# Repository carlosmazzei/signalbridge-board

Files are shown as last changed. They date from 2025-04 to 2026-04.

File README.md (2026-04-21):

<!-- markdownlint-disable MD033 MD041 -->
<div align="center">
Signalbridge
Signalbridge
</div>
<!-- markdownlint-enable MD033 MD041 -->

# Signalbridge - Board




**A comprehensive, industrial-grade breakout board for the Raspberry Pi Pico with advanced I/O expansion and control capabilities.**

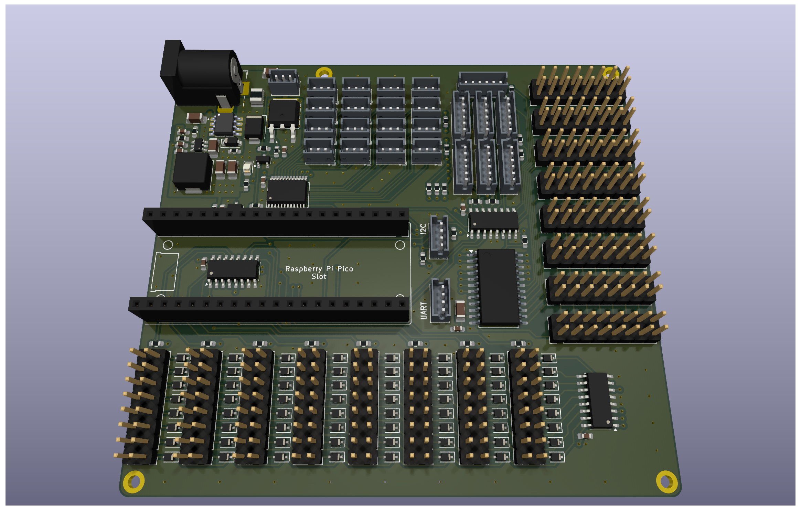
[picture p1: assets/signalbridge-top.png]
Board Render Top

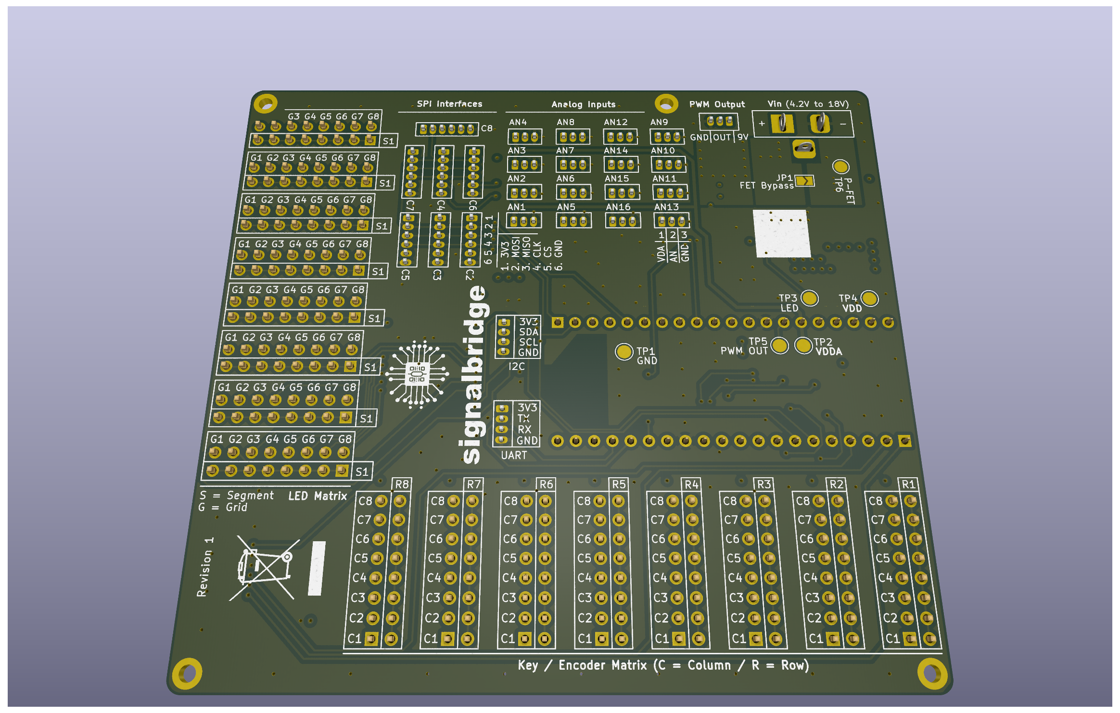
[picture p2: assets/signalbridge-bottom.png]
Board Render Bottom


## Fabricated Board

<!-- markdownlint-disable MD033 -->
<p align="center">
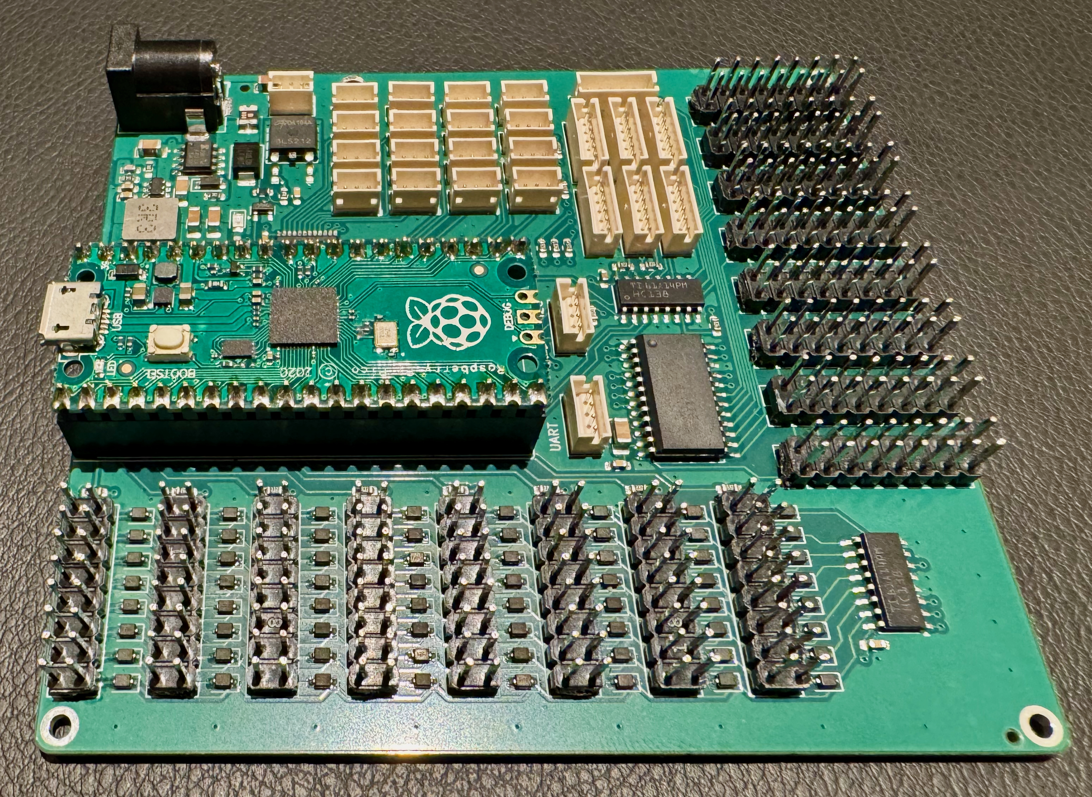
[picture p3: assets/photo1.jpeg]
Fabricated Board - Photo 1
  
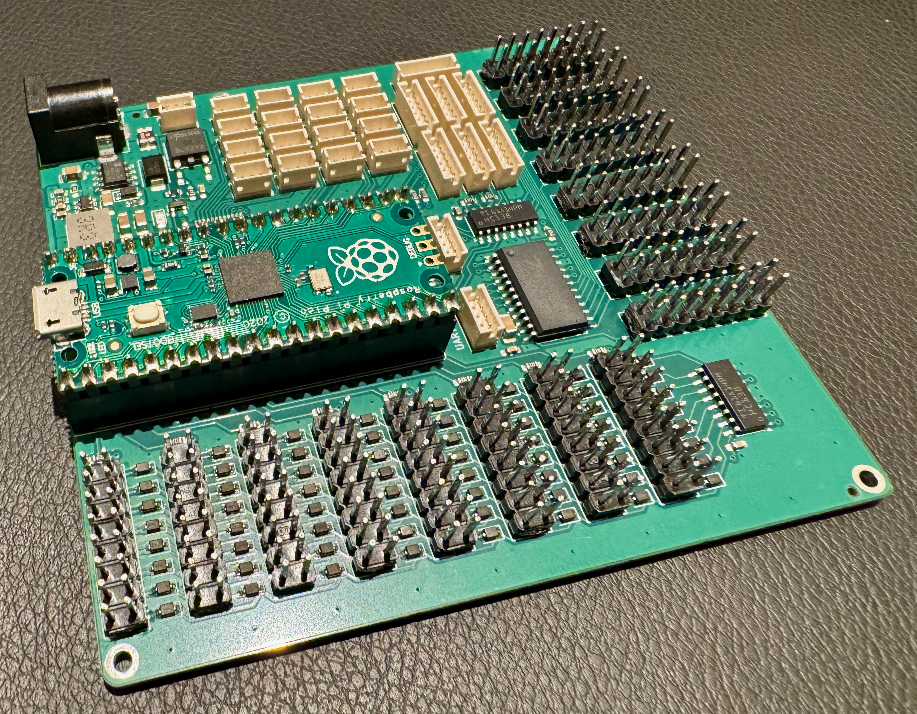
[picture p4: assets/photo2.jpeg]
Fabricated Board - Photo 2
  
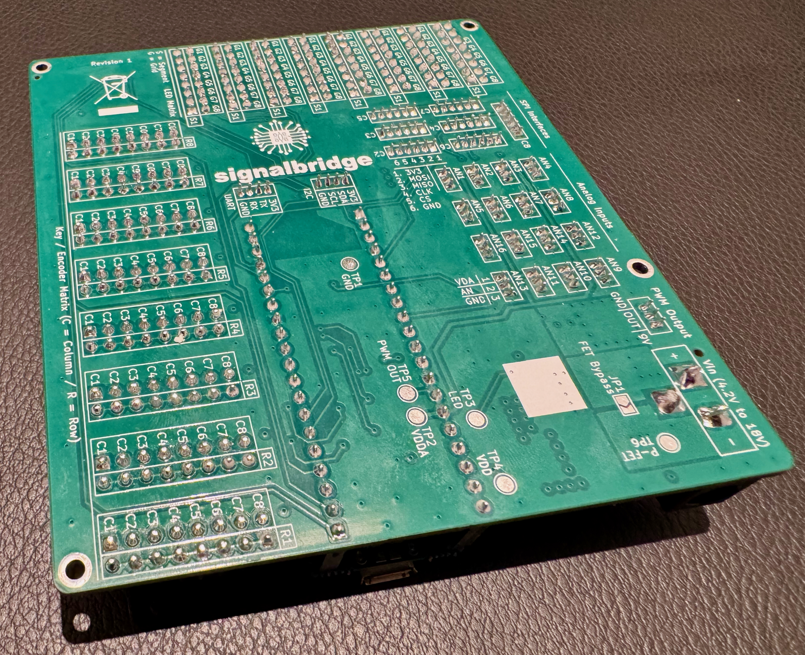
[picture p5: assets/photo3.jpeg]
Fabricated Board - Photo 3
  
</p>
<!-- markdownlint-enable MD033 -->

## Overview

Signalbridge is a feature-rich breakout board designed to unlock the full potential of the Raspberry Pi Pico microcontroller. This board transforms the Pico into a powerful controller suitable for industrial automation, IoT projects, robotics, and educational applications.

> [!TIP]
> This board is designed for the Raspberry Pi Pico.

Related repos:

- [Signalbridge breakout board](https://github.com/carlosmazzei/signalbridge-board) (This repo)
- [Signalbridge test suite](https://github.com/carlosmazzei/signalbridge-test-suite)
- [Signalbridge firmware](https://github.com/carlosmazzei/signalbridge-controller)

### Key Highlights

- **Wide Input Voltage Range**: 4.2V to 18V DC input with efficient 3.3V/3A regulation
- **16-Channel Analog Inputs**: Expandable analog reading capability through integrated multiplexer
- **8×8 Keypad Matrix**: Professional keypad interface with ESD protection
- **Multiple Communication Interfaces**: I2C, UART, and 8 SPI outputs
- **LED Display Controller**: TM1639 for driving 7-segment displays and LED matrices
- **PWM Output**: Dedicated PWM output with 3-pin connector
- **User LED**: Power-on indicator LED
- **Mounting**: 4× mounting holes for secure installation
- **Comprehensive Protection**: ESD protection on all external interfaces
- **Professional Grade**: Designed for reliability and expandability

## Project Structure

```text
signalbridge-board/
├── pi_controller.kicad_{pro,sch,pcb,dru,prl}  # Main KiCad 9 project
├── fp-lib-table, sym-lib-table                # KiCad library tables
├── fabrication-toolkit-options.json           # Fabrication-Toolkit settings
├── library/                                   # Custom symbols & footprints
├── assets/                                    # Board renders & logos
├── datasheets/                                # Component datasheets (PDF)
├── jlcpcb/                                    # Fabrication outputs (gerbers, BOM, CPL)
└── docs/
    └── PRODUCTION_CHECKLIST.md                # PCBA production & test-point checklist
```

The `jlcpcb/` folder name is referenced by `.github/workflows/release_jlcpcb.yml`; the `library/` folder and the root `pi_controller.*` files are referenced by `fp-lib-table` / `sym-lib-table`. Renaming any of these will break the project.

## Features
### Power Management

- **Input Voltage**: 4.2V to 18V DC (via barrel jack connector)
- **Regulation**: AP62300TWU buck converter providing 3.3V at up to 3A
- **Efficiency**: High-efficiency switching regulator with low dropout
- **Protection**: Input protection and power indicator LED
- **Flexibility**: Can be powered via USB or external DC supply

### Analog Inputs (16-Channel)

- **Multiplexer**: CD74HC4067 16:1 analog multiplexer
- **Resolution**: 12-bit ADC resolution (0-4095 digital values)
- **Voltage Range**: 0V to 3.3V analog input range
- **Reference**: Precision LM4040DBZ-3 3.0V voltage reference for accuracy
- **Software Control**: Channel selection via GPIO control lines
- **Connectors**: 16× 3-pin screw terminals for easy field wiring

### Keypad Matrix Interface (8×8)

- **Matrix Size**: 8 rows × 8 columns (64 keys maximum)
- **Connectors**: 2× 16-pin IDC headers for row/column connections
- **Protection**: BAT54J Schottky diodes on every line for ESD protection
- **Pull-ups**: Integrated pull-up resistors for reliable scanning
- **Flexibility**: Supports various keypad sizes up to 8×8

### Communication Interfaces

#### I2C Interface

- **Pins**: SDA (GPIO2), SCL (GPIO3)
- **Pull-ups**: 2.2kΩ pull-up resistors to 3.3V
- **Connector**: 4-pin terminal block (VCC, GND, SDA, SCL)
- **Voltage**: 3.3V logic levels

#### UART Interface  

- **Pins**: TX (GPIO0), RX (GPIO1)
- **Connector**: 4-pin terminal block (VCC, GND, TX, RX)
- **Voltage**: 3.3V logic levels
- **Usage**: Serial communication, debugging, or external device control

#### SPI Interfaces (8 Outputs)

- **Outputs**: 8× independent SPI chip select lines
- **Connectors**: 6-pin headers per SPI output
- **Pinout**: VCC, GND, MOSI, MISO, SCLK, CS
- **Shared Bus**: Common MOSI, MISO, SCLK with individual chip selects
- **Applications**: Multiple SPI devices, sensor networks, display modules

### Display Controller

- **IC**: TM1639 LED display controller
- **Interface**: 3-wire serial (DIO, CLK, STB)
- **Capability**: Drive 8×8 LED matrix or multiple 7-segment displays
- **Features**: Built-in key scanning, adjustable brightness, minimal GPIO usage
- **Connector**: 6-pin header with standard TM1639 pinout

### Additional I/O

- **PWM Output**: Dedicated PWM output with 3-pin connector
- **Test Points**: Multiple test points for debugging and measurement
- **User LED**: Power-on indicator LED
- **Mounting**: 4× mounting holes for secure installation

## Technical Specifications

### Electrical Characteristics

| Parameter | Min | Typ | Max  | Unit |
| --- | --- | --- | ---- | ---- |
| Input Voltage | 4.2 | 9.0 | 18.0 | V |
| Output Voltage | - | 3.3 | - | V |
| Output Current | - | - | 3.0  | A |
| ADC Resolution | - | 12  | - | bits |
| ADC Reference | - | 3.0 | - | V |
| Operating Temperature | -20 | 25  | 85 | °C |

### Physical Dimensions

- **PCB Size**: 99.7 × 99.1 mm
- **Mounting Holes**: 4× M3 holes
- **Connector Types**: Screw terminals, pin headers, IDC connectors
- **Layer Count**: 4-layer PCB design

## Hardware Setup

### 1. Power Connection

- DC Input: Connect 4.2V to 18V DC to J2 barrel connector
- USB Power: Connect USB cable to Raspberry Pi Pico (alternative)

### 2. Analog Inputs (AN1-AN16)

- Signal Range: 0V to 3.3V maximum
- Connector: 3-pin screw terminals
- Pinout: Signal, VDDA, GND

### 3. Keypad Matrix

- Row Connector (JR1-JR8): Connect keypad rows 1-8
- Column Connector: Connect keypad columns 1-8
- Matrix Size: Up to 8×8 (64 keys)

### 4. Communication Interfaces

- I2C (J30): VCC(3.3V), GND, SDA, SCL
- UART (J31): VCC(3.3V), GND, TX, RX  
- SPI (JSPI1-JSPI7): VCC, GND, MOSI, MISO, SCLK, CS

## Assembly Instructions

### Required Components

- 1× Raspberry Pi Pico (with headers soldered)
- 1× Signalbridge PCB
- Connectors (screw terminals, pin headers as needed)
- Power supply (4.2V to 18V DC)

### Assembly Steps

1. **Inspect PCB**: Check for any manufacturing defects
2. **Install Raspberry Pi Pico**: Insert Pico into main socket (U4 position)
3. **Connect Power**: Wire DC supply to J2 barrel connector
4. **Test Power**: Verify 3.3V output and LED indicator
5. **Install Connectors**: Solder required connectors for your application
6. **Test Interfaces**: Verify I2C, SPI, and ADC functionality

### Troubleshooting

- **No Power LED**: Check input voltage and connections
- **ADC Readings Incorrect**: Verify voltage reference and input range
- **I2C Not Working**: Check pull-up resistors and wiring
- **Keypad Issues**: Verify matrix connections and ESD protection

## Pin Assignments

### Raspberry Pi Pico Pin Usage

| GPIO  | Function  | Description |
| ----- | --- | --- |
| 0 | UART0_TX  | UART transmit |
| 1 | UART0_RX  | UART receive |
| 2 | SDA | I2C data line |
| 3 | SCL | I2C clock line |
| 4-9 | ROW1-ROW6 | Keypad matrix rows |
| 10 | ADC_MUX_A | ADC multiplexer control A |
| 11 | ADC_MUX_B | ADC multiplexer control B |
| 12 | ADC_MUX_C | ADC multiplexer control C |
| 13 | ADC_MUX_D | ADC multiplexer control D |
| 14-21 | COL1-COL8 | Keypad matrix columns |
| 22 | PWM_OUT | PWM output |
| 26 | ADC0 | Multiplexed analog input  |
| 27 | CS_LED | TM1639 strobe |
| 28 | CS_KEY | TM1639 data I/O |

### SPI Chip Select Assignments

| Signal | GPIO | Description  |
| --- | --- | --- |
| CS1 | GPIO5  | SPI device 1 |
| CS2 | GPIO6  | SPI device 2 |
| CS3 | GPIO7  | SPI device 3 |
| CS4 | GPIO8  | SPI device 4 |
| CS5 | GPIO9  | SPI device 5 |
| CS6 | GPIO16 | SPI device 6 |
| CS7 | GPIO17 | SPI device 7 |
| CS8 | GPIO18 | SPI device 8 |

### Shared SPI Signals

| Signal | GPIO | Description |
| --- | --- | --- |
| MOSI | GPIO19 | SPI Master Out, Slave In |
| MISO | GPIO20 | SPI Master In, Slave Out |
| SCLK | GPIO21 | SPI Clock |

## Safety and Compliance

### Electrical Safety

- Input voltage: 4.2V to 18V DC only
- Maximum current: 3A output
- ESD protection: BAT54J diodes on all external interfaces
- Reverse polarity: Protected by input diode

### Usage Guidelines

- Do not exceed maximum input voltage (18V)
- Ensure proper grounding for all analog measurements
- Use appropriate wire gauge for current requirements
- Follow proper ESD handling procedures

## License

This project is released under the [**CERN Open Hardware Licence**](LICENSE).

## Contributing

We welcome contributions to improve Signalbridge! Here's how you can help:

### Hardware Improvements

- PCB layout optimizations
- Additional connector options
- Component substitutions for better availability
- Cost reduction improvements

### Software Development

- Additional driver libraries
- Example projects
- Documentation improvements
- Bug fixes and optimizations

### How to Contribute

1. Fork the repository
2. Create a feature branch (`git checkout -b feature/amazing-feature`)
3. Commit your changes (`git commit -m 'Add amazing feature'`)
4. Push to the branch (`git push origin feature/amazing-feature`)
5. Open a Pull Request

### Issue Reporting

Please use GitHub Issues to report:

- Hardware design problems
- Software bugs
- Documentation errors
- Feature requests

## Support

### Community Support

- **GitHub Issues**: Report bugs and request features
- **Discussions**: General questions and project sharing
- **Wiki**: Community-maintained documentation

### Documentation

- **Schematic**: Detailed circuit diagrams
- **PCB Layout**: Layer stackup and routing
- **Assembly Guide**: Step-by-step assembly instructions
- **User Manual**: Comprehensive usage guide

## Acknowledgments

- **Raspberry Pi Foundation** for the excellent Pico microcontroller
- **KiCad Development Team** for the outstanding PCB design tools
- **Open Source Community** for inspiration and shared knowledge
- **Component Manufacturers** for detailed datasheets and application notes

## Roadmap

### Version 2.0 Features (Planned)

- [ ] USB-C connector option
- [ ] CAN bus interface

### Long-term Goals

- [ ] Industrial enclosure design
- [ ] DIN rail mounting option
- [ ] Higher current power supply (5A)
- [ ] Isolated I/O options
- [ ] Professional certification (CE, FCC)

---

Made with care for the maker community

Signalbridge - Expanding the possibilities of Raspberry Pi Pico

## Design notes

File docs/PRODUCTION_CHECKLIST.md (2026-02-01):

# Production Checklist for Raspberry Pi Pico Breakout Boards

This checklist is intended to help ensure that your Raspberry Pi Pico breakout board design is ready for production, whether you are assembling it yourself (DIY) or sending it to a contract manufacturer (PCBA). It covers key areas such as design verification, bill of materials (BOM) accuracy, assembly considerations, and test point inclusion.

## Additional PCBA (Assembly) Checklist

Use this section if the board will be assembled by a factory (turnkey or consigned).

### A) BOM correctness and availability

- [ ] Export a **clean BOM** (MPN + manufacturer + description + value + package + quantity).
- [ ] Ensure **every line** has a valid **Manufacturer Part Number (MPN)** (avoid “generic” unless intentionally flexible).
- [ ] Prefer **in-stock / active lifecycle** parts (avoid NRND/EOL when possible).
- [ ] For each critical component, provide at least one **approved alternate** (same footprint + same key specs).
- [ ] Verify **tolerance/voltage/power** ratings:
  - [ ] Resistors: power rating (e.g., 0.1W vs 0.25W), tolerance
  - [ ] Capacitors: voltage derating (X5R/X7R loss), temp range
  - [ ] Inductors (if any): saturation current, DCR
  - [ ] Diodes/TVS: standoff voltage, peak power
- [ ] Check **package availability** (0402/0201 can raise cost/yield risk; use 0603/0805 when acceptable).
- [ ] Confirm all passives have **standard values** (avoid exotic values unless needed).
- [ ] If using a specific assembler’s catalog (e.g., JLC/LCSC), verify:
  - [ ] Correct library part number (e.g., LCSC code) is included
  - [ ] “Basic/Preferred” vs “Extended” parts are intentional (cost/lead time impact)
  - [ ] Stock levels cover the required quantity + spares

### B) Footprints, polarity, and pick-and-place orientation

- [ ] Verify **pin 1** marking is clear on footprint and silkscreen for all ICs.
- [ ] Verify polarity for:
  - [ ] LEDs (anode/cathode)
  - [ ] Diodes/TVS
  - [ ] Electrolytics/tantalums
  - [ ] Any keyed connectors
- [ ] Confirm the footprint origin/centroid is correct (especially for connectors and large parts).
- [ ] Check **rotation conventions** (0/90/180/270) against the assembler’s expected orientation.
- [ ] Ensure all SMD parts are placed on the **correct side** (Top/Bottom) per assembly plan.
- [ ] If assembling both sides:
  - [ ] Confirm the assembler supports it and the process constraints are met
  - [ ] Avoid heavy parts on the second-reflow side unless allowed

### C) Placement rules (DFM/DFA)

- [ ] Check **component-to-component clearance** meets assembler minimums (including courtyards).
- [ ] Maintain a **keepout** around board edges as required by panel rails/handling (typ. 3–5 mm; follow assembler spec).
- [ ] Keep components away from:
  - [ ] Mounting holes (tool access + washers)
  - [ ] Fiducials
  - [ ] Panel breakaway tabs / mouse-bites / V-cuts
- [ ] Ensure adequate **soldering access** for any through-hole parts (if wave/selective/hand-solder is used).
- [ ] Use **thermal reliefs** for through-hole pads tied to planes (hand-solder friendliness).
- [ ] Review very small passives near connectors/edges (risk of tombstoning/damage).

### D) Solder paste and stencil considerations

- [ ] Review paste apertures for fine-pitch parts (if any) to avoid bridging.
- [ ] For large exposed pads (if any), consider paste windowing to prevent float/voiding.
- [ ] Avoid uneven copper/paste that can cause **tombstoning** (especially on 0402/0201).
- [ ] Confirm solder mask expansion avoids accidental mask-defined pads unless intentional.

### E) Fiducials, tooling holes, and panelization

- [ ] Add at least **3 global fiducials** on the assembled side (and on the opposite side if double-sided).
- [ ] Add **local fiducials** near fine-pitch ICs (if present).
- [ ] Include **tooling holes** if your assembler requires them (often 2–4).
- [ ] Confirm panelization approach:
  - [ ] Single board vs panel
  - [ ] V-score vs tabs/mouse-bites
  - [ ] Rails width and component keepout on rails

### F) Assembly outputs and documentation package

- [ ] Generate **Pick-and-Place / CPL** with correct:
  - [ ] RefDes
  - [ ] X/Y coordinates
  - [ ] Rotation
  - [ ] Side (Top/Bottom)
- [ ] Provide **Assembly drawings** (PDF) for Top/Bottom with:
  - [ ] RefDes
  - [ ] Polarity markers
  - [ ] Connector orientation notes
- [ ] Provide **Gerbers** + **drill files** as usual, plus:
  - [ ] Paste layers (`F.Paste`/`B.Paste`) if stencil is ordered
  - [ ] Fab notes (stack-up, finish, thickness, soldermask color if relevant)
- [ ] If connectors are not to be populated, clearly mark **DNP/DNI** parts in BOM and assembly notes.
- [ ] Include a **test plan** (even minimal):
  - [ ] Power rails check points (3V3, VSYS, GND)
  - [ ] UART header loopback test pads (optional)
  - [ ] I²C pull-up verification points
  - [ ] SPI continuity checks (SCK/MOSI/MISO/CS)

### G) Supply chain / risk checks (recommended)

- [ ] Identify single-source parts (connectors, regulators, crystals) and define alternates.
- [ ] Flag long lead-time parts and verify ordering strategy (turnkey vs consigned).
- [ ] Confirm RoHS/REACH requirements if needed.
- [ ] Confirm moisture sensitivity (MSL) handling requirements for any sensitive packages (rare in simple breakouts, but good practice).

---

## Test Points (PCBA + Bring-up) Checklist

Add/verify test points to make assembly test, debugging, and production bring-up reliable.

### A) Power test points (mandatory)

- [ ] Add clearly labeled test points for:
  - [ ] `GND` (at least 2, preferably near opposite sides of the board)
  - [ ] `3V3`
  - [ ] `VSYS` / `VBUS` / `5V` (whichever rails exist on the board)
- [ ] Place at least one `GND` test point close to each power rail test point (probe-friendly).
- [ ] Ensure power test points are reachable with probes after assembly (not blocked by tall connectors).

### B) Interface test points (recommended)

- [ ] SPI test points (if exposed via headers, still add near the Pico for debug):
  - [ ] `SPI_SCK`
  - [ ] `SPI_MOSI`
  - [ ] `SPI_MISO`
  - [ ] `SPI_CS` (or at least one representative CS)
- [ ] I²C test points:
  - [ ] `I2C_SDA`
  - [ ] `I2C_SCL`
- [ ] UART test points:
  - [ ] `UART_TX`
  - [ ] `UART_RX`
- [ ] Add at least one nearby `GND` test point for clean signal probing (especially for SPI SCK).

### C) Reset / boot / debug (if applicable)

- [ ] Add test points for key control signals as applicable:
  - [ ] `RUN` / `RESET` (Pico reset line)
  - [ ] `BOOTSEL` (if routed out)
- [ ] If SWD is available on the design, add a test point/header for:
  - [ ] `SWDIO`
  - [ ] `SWCLK`
  - [ ] `GND`
  - [ ] `3V3` (reference)

### D) Placement and probing rules

- [ ] Use consistent test point style:
  - [ ] Prefer dedicated test point footprints (round pad) over bare vias.
  - [ ] Minimum exposed pad diameter per assembler/test method (typ. ≥ 1.0 mm; follow assembler spec).
- [ ] Maintain adequate spacing between test points for probes (typ. ≥ 1.0–1.5 mm; follow probe type).
- [ ] Keep test points away from board edges/panel break tabs/rails keepouts.
- [ ] Ensure test points are on the intended side for test (usually Top side for pogo fixtures).
- [ ] Avoid placing test points under connectors, Pico module overhang, or other tall parts.

### E) Electrical correctness and labeling

- [ ] Confirm each test point is assigned to the correct **net** (no accidental net ties).
- [ ] Ensure silkscreen labels are readable:
  - [ ] Use short, unambiguous labels (`TP_GND`, `TP_3V3`, `TP_SCK`, etc.).
- [ ] If the design uses multiple grounds (e.g., `AGND/PGND`), ensure test points reflect the intended net (prefer a single solid GND unless there is a clear reason).

### F) Factory test support (optional but valuable)

- [ ] Add a dedicated `TP_GND` and `TP_3V3` pair near where a fixture would clamp/probe.
- [ ] Consider adding a simple production test header/pads for quick checks:
  - [ ] `GND`, `3V3`, `UART_TX`, `UART_RX` (minimum set)
- [ ] Document expected bring-up measurements in the assembly/test notes:
  - [ ] `3V3` nominal range
  - [ ] `VSYS/VBUS` nominal range (if present)
  - [ ] Idle levels for UART/I²C lines (pull-ups, etc.)

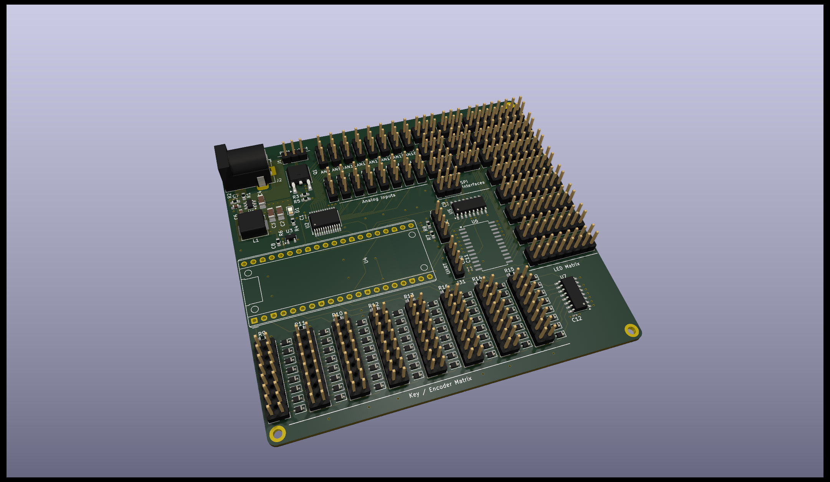
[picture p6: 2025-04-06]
pi_controller.png

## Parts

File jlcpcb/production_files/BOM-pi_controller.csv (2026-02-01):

Comment | Designator | Footprint | LCSC | Quantity
Z2SMBJ18A | D66 | D_SMB | C10212 | 1
22uF | C17,C2,C3 | C_1206_3216Metric_Pad1.33x1.80mm_HandSolder | C12891 | 3
CD74HC4051M96 | U8 | SOIC-16_3.9x9.9mm_P1.27mm | C132065 | 1
10uF | C4 | C_1206_3216Metric_Pad1.33x1.80mm_HandSolder | C13585 | 1
0.1uF | C1,C11,C12,C13,C16,C9 | C_0603_1608Metric_Pad1.08x0.95mm_HandSolder | C14663 | 6
100pF | C7 | C_0603_1608Metric_Pad1.08x0.95mm_HandSolder | C14858 | 1
100uF | C10 | C_1206_3216Metric_Pad1.33x1.80mm_HandSolder | C15008 | 1
1nF | C14 | C_0603_1608Metric_Pad1.08x0.95mm_HandSolder | C1588 | 1
470nF | C5 | C_0603_1608Metric_Pad1.08x0.95mm_HandSolder | C1623 | 1
I2C | J30,J31 | JST_ZH_B4B-ZR_1x04_P1.50mm_Vertical_SilkSafe | C163034 | 2
AP62300TWU | U1 | TSOT-23-6 | C1883519 | 1
BZT52C12 | D67 | D_SOD-123 | C19077410 | 1
MMBT3904 | Q2 | SOT-23 | C20526 | 1
TM1639 (TA2009B) | U6 | SOP-24_7.5x15.4mm_P1.27mm | C20611984 | 1
220nF | C6 | C_0603_1608Metric_Pad1.08x0.95mm_HandSolder | C21120 | 1
Polyfuse | F1 | Fuse_1210_3225Metric_Pad1.42x2.65mm_HandSolder | C22379947 | 1
10R | R18 | R_0603_1608Metric_Pad0.98x0.95mm_HandSolder | C22859 | 1
LED | D1 | LED_0805_2012Metric_Pad1.15x1.40mm_HandSolder | C2297 | 1
3.3k | R10,R11,R12,R13,R14,R15,R16,R9 | R_0603_1608Metric_Pad0.98x0.95mm_HandSolder | C22978 | 8
33.2k | R2 | R_0603_1608Metric_Pad0.98x0.95mm_HandSolder | C23003 | 1
330R | R4 | R_0603_1608Metric_Pad0.98x0.95mm_HandSolder | C23138 | 1
4.7k | R19,R20,R21,R22,R23,R24,R25,R26,R27,R28,R29 | R_0603_1608Metric_Pad0.98x0.95mm_HandSolder | C23162 | 11
47R | R6 | R_0603_1608Metric_Pad0.98x0.95mm_HandSolder | C23182 | 1
2.2uF | C8 | C_0603_1608Metric_Pad1.08x0.95mm_HandSolder | C23630 | 1
10k | R1,R30,R5 | R_0603_1608Metric_Pad0.98x0.95mm_HandSolder | C25804 | 3
BAT54J | D10,D11,D12,D13,D14,D15,D16,D17,D18,D19,D2,D20,D21,D22,D23,D24,D25,D26,D27,D28,D29,D3,D30,D31,D32,D33,D34,D35,D36,D37,D38,D39,D4,D40,D41,D42,D43,D44,D45,D46,D47,D48,D49,D5,D50,D51,D52,D53,D54,D55,D56,D57,D58,D59,D6,D60,D61,D62,D63,D64,D65,D7,D8,D9 | D_SOD-323F | C358488 | 64
DC Supply | J2 | BarrelJack_Horizontal | C381116 | 1
2.2k | R17,R7,R8 | R_0603_1608Metric_Pad0.98x0.95mm_HandSolder | C4190 | 3
LM4040DBZ-3 | U3 | SOT-23 | C460608 | 1
AN1 | AN1,AN10,AN11,AN12,AN13,AN14,AN15,AN16,AN2,AN3,AN4,AN5,AN6,AN7,AN8,AN9,J1 | JST_ZH_B3B-ZR_1x03_P1.50mm_Vertical_SilkSafe | C495558 | 17
Conn_01x06 | JSPI1,JSPI2,JSPI3,JSPI4,JSPI5,JSPI6,JSPI7 | JST_ZH_B6B-ZR_1x06_P1.50mm_Vertical_SilkSafe | C495631 | 7
3.3uH | L1 | L_Sunlord_MWSA0604S | C5189747 | 1
Conn_01x20 | J3,J4 | PinSocket_1x20_P2.54mm_Vertical | C5224030 | 2
1.5k | R3 | R_0603_1608Metric_Pad0.98x0.95mm_HandSolder | C543357 | 1
74HC138 | U5,U7 | SOIC-16_3.9x9.9mm_P1.27mm | C6818 | 2
47uF | C15 | C_1206_3216Metric_Pad1.33x1.80mm_HandSolder | C76659 | 1
LED6 | J26,J27,J28,J29,J32,J33,J34,J35,JR1,JR2,JR3,JR4,JR5,JR6,JR7,JR8 | PinHeader_2x08_P2.54mm_Vertical | C779499 | 16
CD74HC4067SM96 | U2 | SSOP-24_5.3x8.2mm_P0.65mm | C98457 | 1
AOD4184A | Q1 | DPAK228P994X240-4N | C99124 | 1
AO4407A | Q3 | SOIC127P600X175-8N |  | 1

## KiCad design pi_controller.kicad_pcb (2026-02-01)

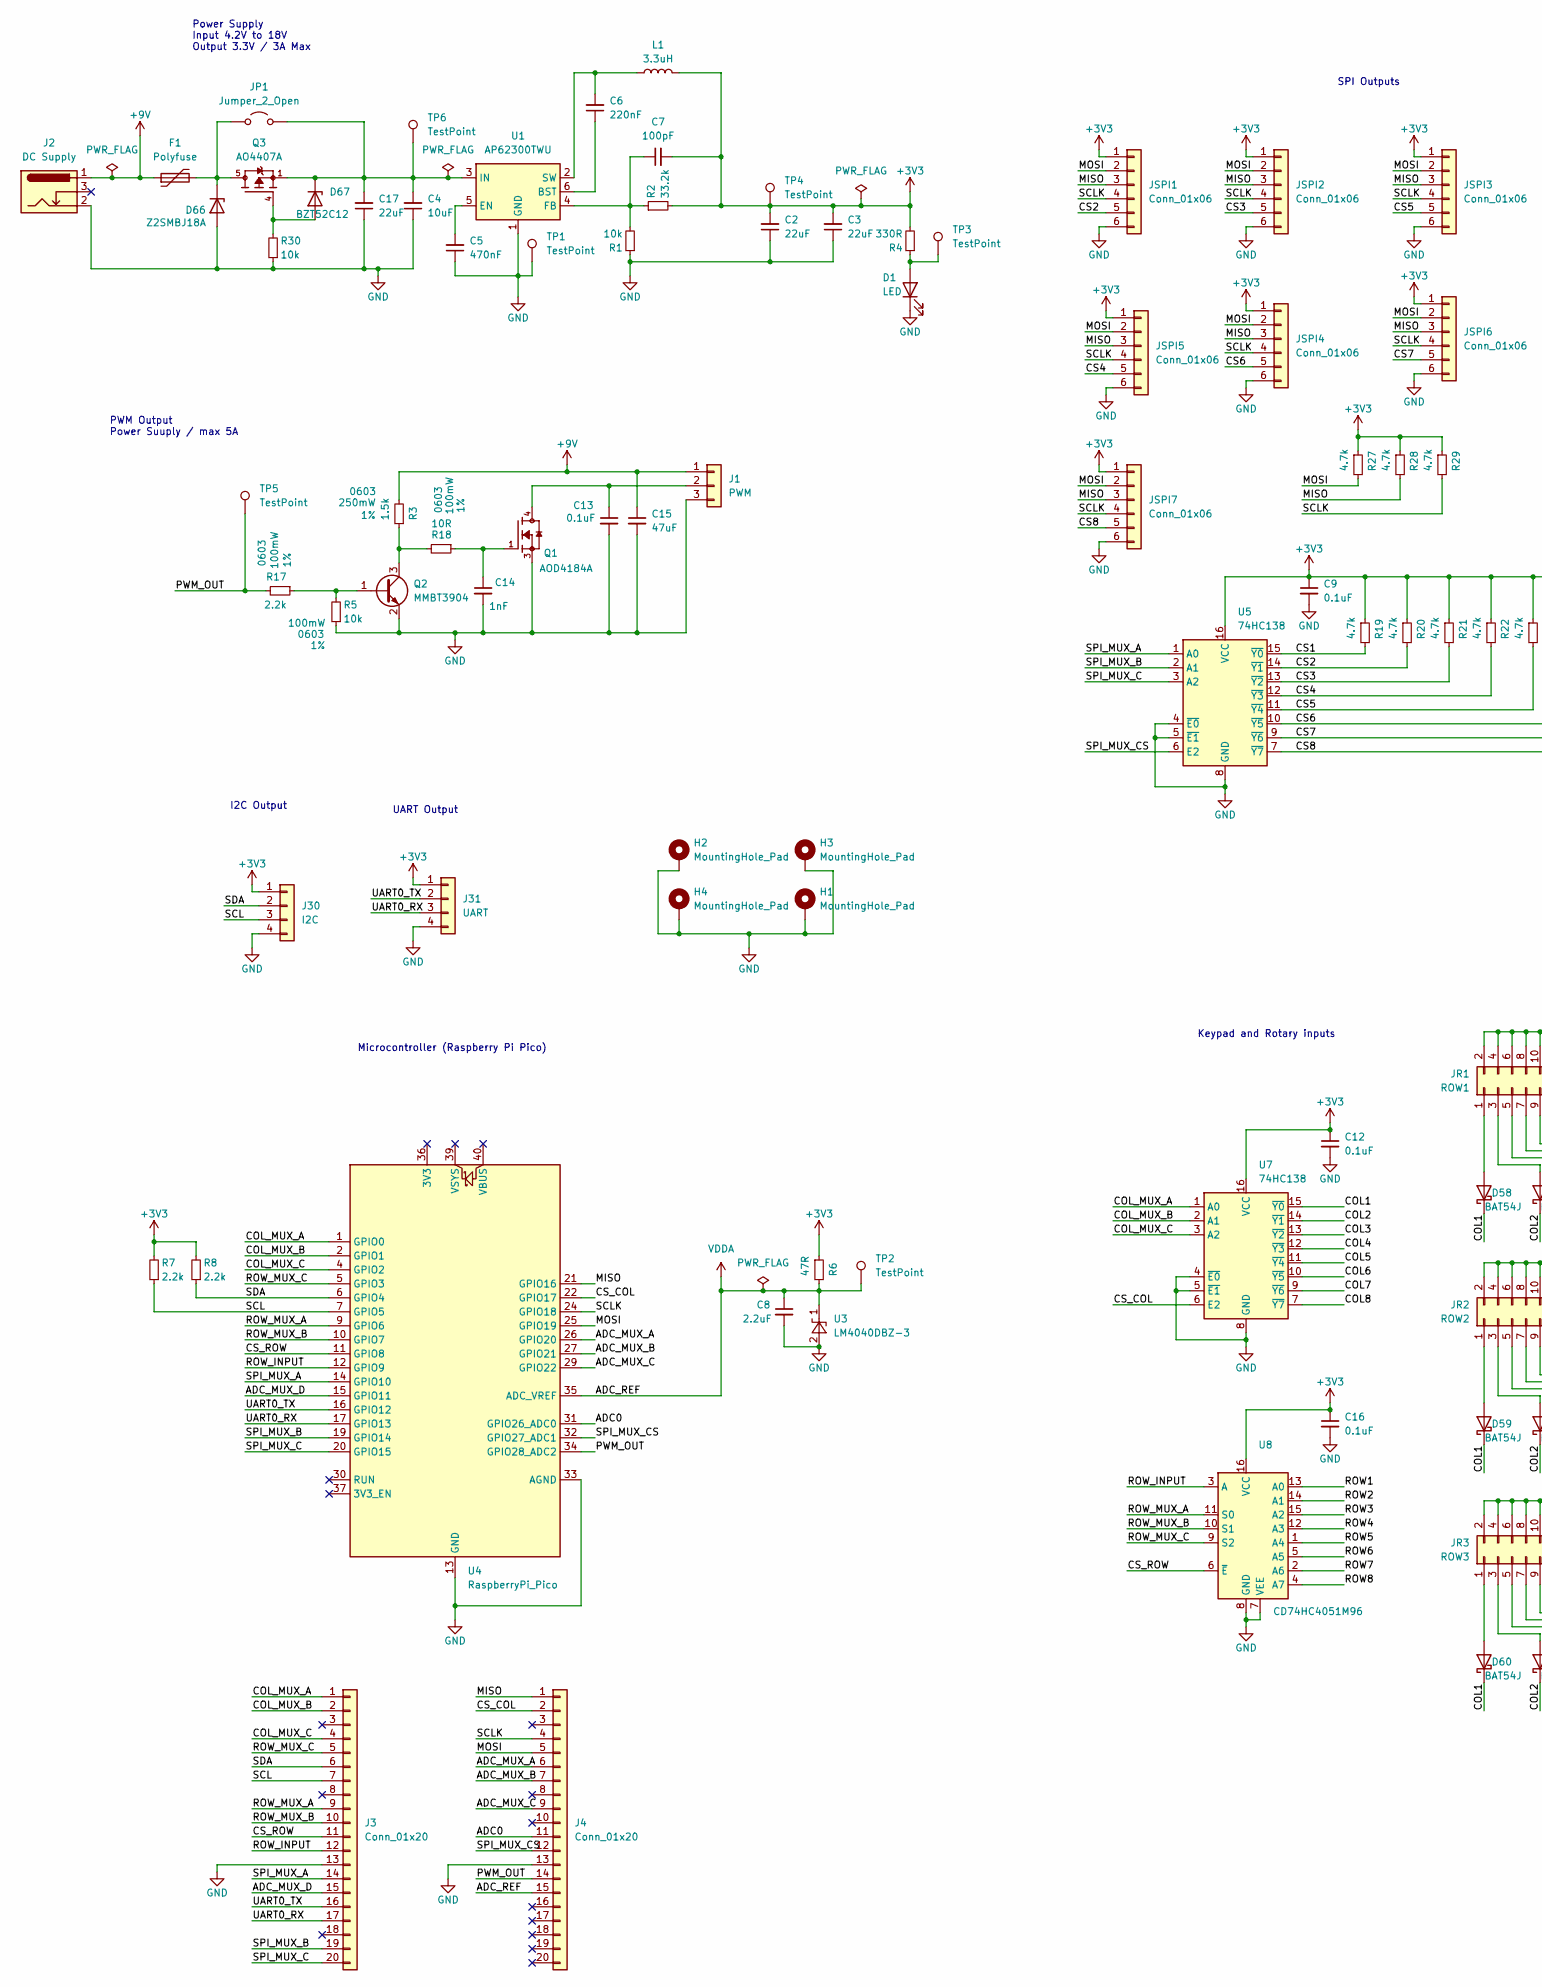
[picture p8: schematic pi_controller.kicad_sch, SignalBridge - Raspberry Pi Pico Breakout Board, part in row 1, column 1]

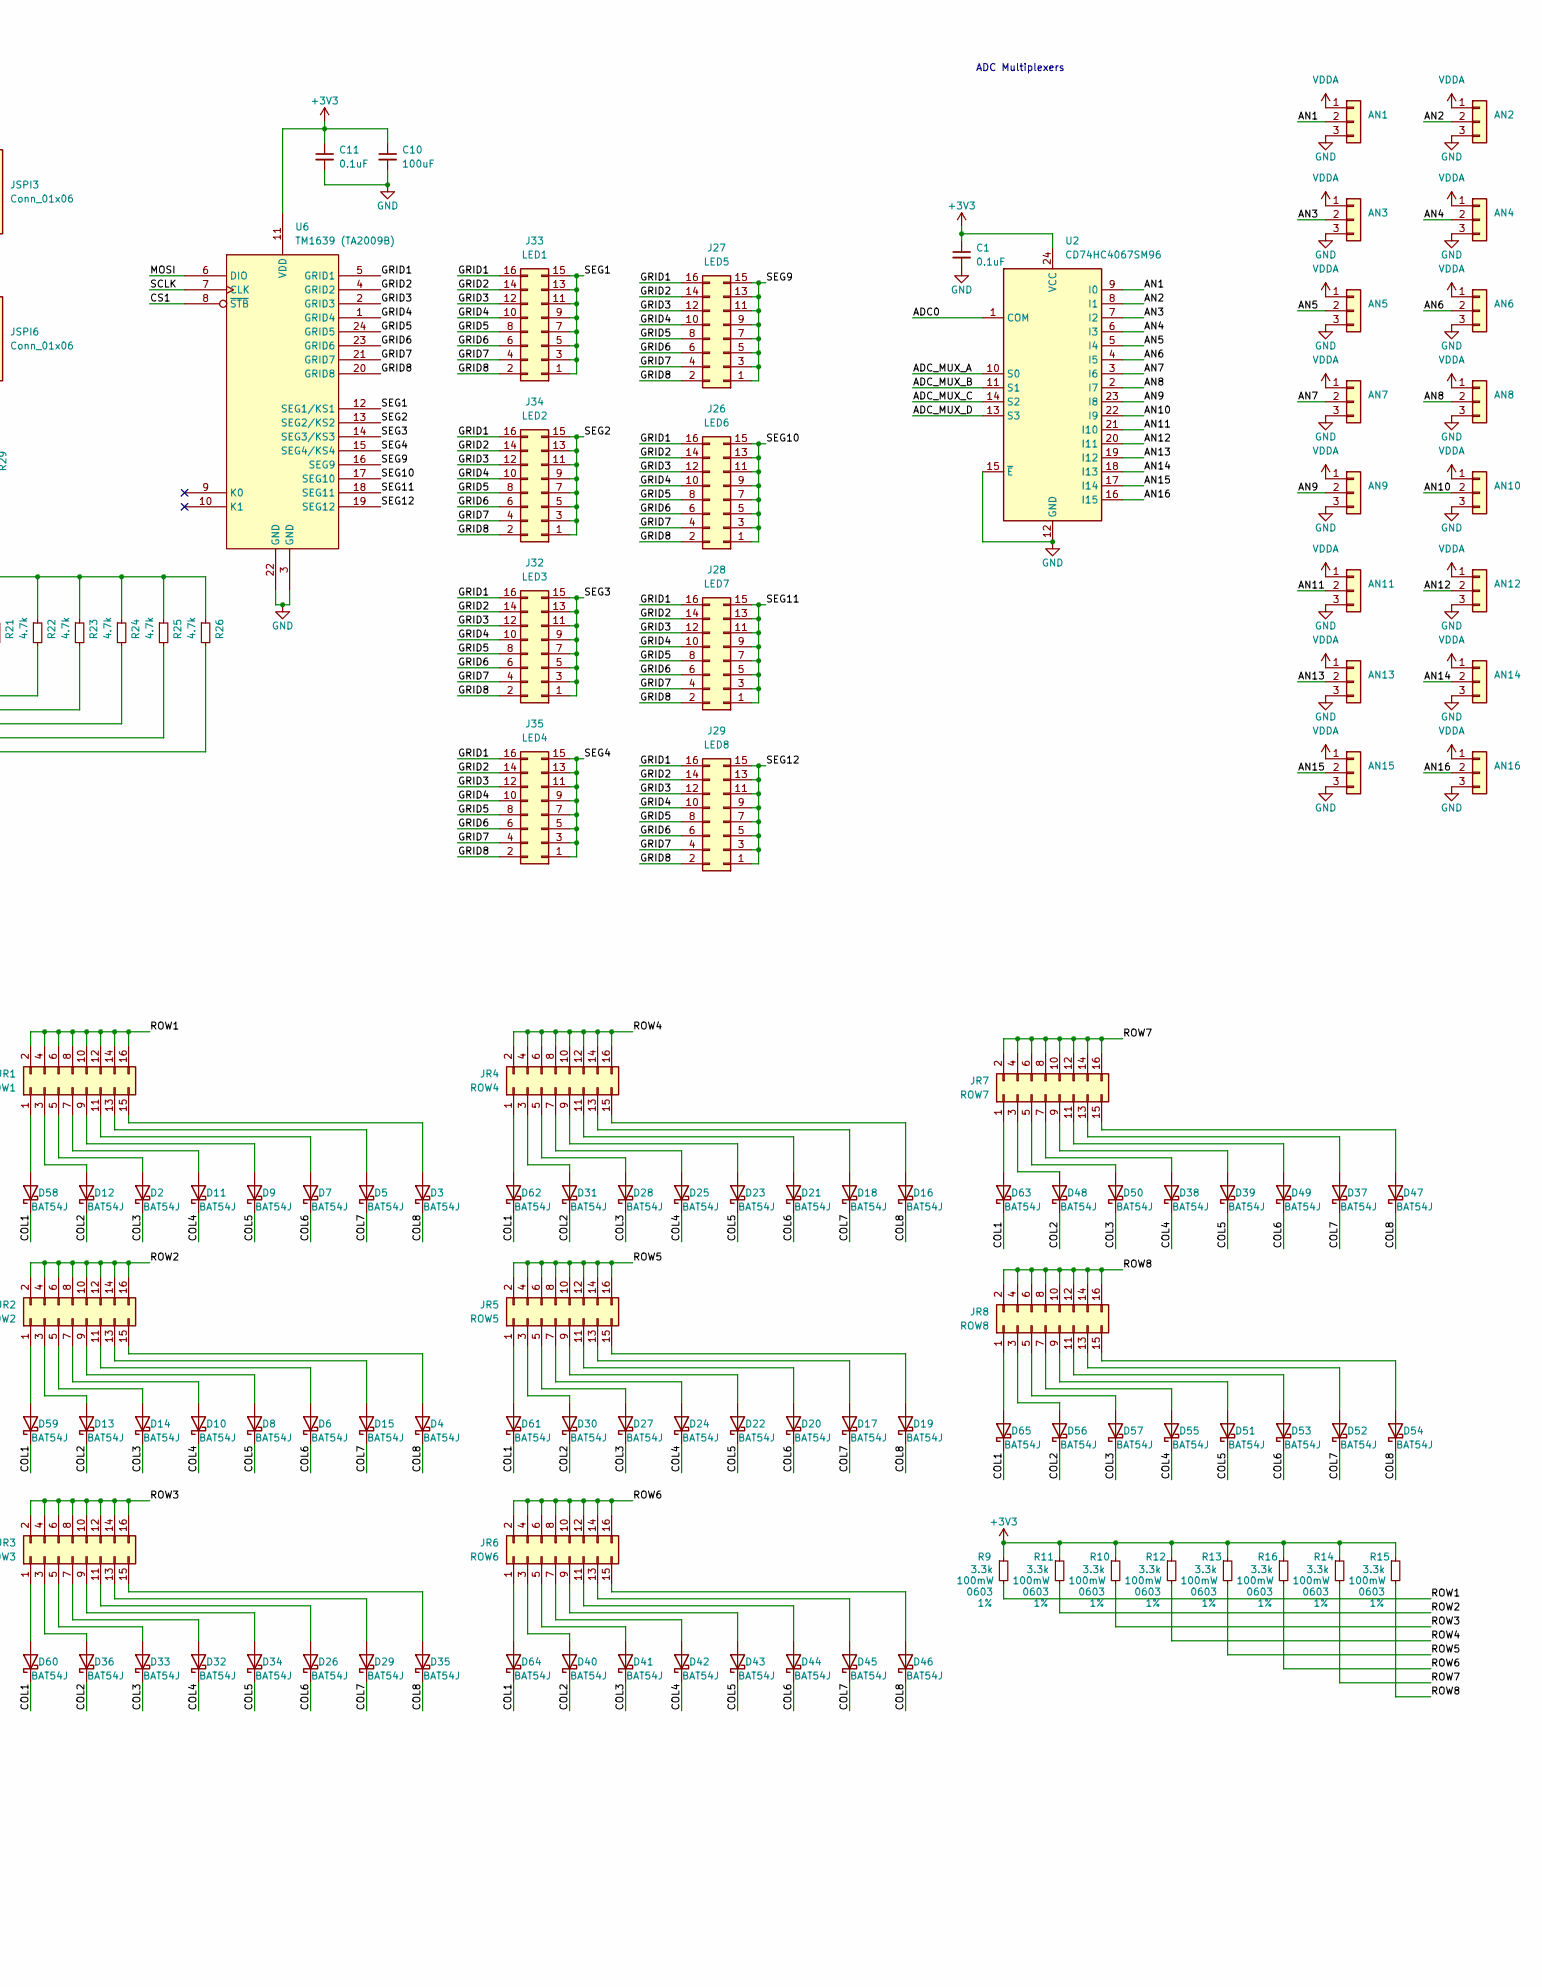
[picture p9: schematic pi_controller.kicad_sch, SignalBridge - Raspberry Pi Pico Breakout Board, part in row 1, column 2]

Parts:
AN1: AN1; JST_ZH_B3B-ZR_1x03_P1.50mm_Vertical_SilkSafe; LCSC PN C495558
AN2: AN2; JST_ZH_B3B-ZR_1x03_P1.50mm_Vertical_SilkSafe; LCSC PN C495558
AN3: AN3; JST_ZH_B3B-ZR_1x03_P1.50mm_Vertical_SilkSafe; LCSC PN C495558
AN4: AN4; JST_ZH_B3B-ZR_1x03_P1.50mm_Vertical_SilkSafe; LCSC PN C495558
AN5: AN5; JST_ZH_B3B-ZR_1x03_P1.50mm_Vertical_SilkSafe; LCSC PN C495558
AN6: AN6; JST_ZH_B3B-ZR_1x03_P1.50mm_Vertical_SilkSafe; LCSC PN C495558
AN7: AN7; JST_ZH_B3B-ZR_1x03_P1.50mm_Vertical_SilkSafe; LCSC PN C495558
AN8: AN8; JST_ZH_B3B-ZR_1x03_P1.50mm_Vertical_SilkSafe; LCSC PN C495558
AN9: AN9; JST_ZH_B3B-ZR_1x03_P1.50mm_Vertical_SilkSafe; LCSC PN C495558
AN10: AN10; JST_ZH_B3B-ZR_1x03_P1.50mm_Vertical_SilkSafe; LCSC PN C495558
AN11: AN11; JST_ZH_B3B-ZR_1x03_P1.50mm_Vertical_SilkSafe; LCSC PN C495558
AN12: AN12; JST_ZH_B3B-ZR_1x03_P1.50mm_Vertical_SilkSafe; LCSC PN C495558
AN13: AN13; JST_ZH_B3B-ZR_1x03_P1.50mm_Vertical_SilkSafe; LCSC PN C495558
AN14: AN14; JST_ZH_B3B-ZR_1x03_P1.50mm_Vertical_SilkSafe; LCSC PN C495558
AN15: AN15; JST_ZH_B3B-ZR_1x03_P1.50mm_Vertical_SilkSafe; LCSC PN C495558
AN16: AN16; JST_ZH_B3B-ZR_1x03_P1.50mm_Vertical_SilkSafe; LCSC PN C495558
C1, C11, C12, C16: 0.1uF; C_0603_1608Metric_Pad1.08x0.95mm_HandSolder; Voltage Rating 50V; Tolerance 10%; LCSC PN C14663
C2, C3, C17: 22uF; C_1206_3216Metric_Pad1.33x1.80mm_HandSolder; Temperature Rating X5R; Tolerance 10%; LCSC PN C12891
C4: 10uF; C_1206_3216Metric_Pad1.33x1.80mm_HandSolder; Voltage Rating 50V; Tolerance 10%; LCSC PN C13585
C5: 470nF; C_0603_1608Metric_Pad1.08x0.95mm_HandSolder; Voltage Rating 25V; Tolerance 10%; LCSC PN C1623
C6: 220nF; C_0603_1608Metric_Pad1.08x0.95mm_HandSolder; Tolerance 10%; Voltage Rating 25V; LCSC PN C21120
C7: 100pF; C_0603_1608Metric_Pad1.08x0.95mm_HandSolder; Tolerance 10%; Voltage Rating 50V; LCSC PN C14858
C8: 2.2uF; C_0603_1608Metric_Pad1.08x0.95mm_HandSolder; Voltage Rating 16V; Tolerance 10%; LCSC PN C23630
C9: 0.1uF; C_0603_1608Metric_Pad1.08x0.95mm_HandSolder; Tolerance 5%; Voltage Rating 50V; LCSC PN C14663
C10: 100uF; C_1206_3216Metric_Pad1.33x1.80mm_HandSolder; Voltage Rating 50V; Tolerance 10%; LCSC PN C15008
C13: 0.1uF; C_0603_1608Metric_Pad1.08x0.95mm_HandSolder; Tolerance 10%; Voltage Rating 50V; LCSC PN C14663
C14: 1nF; C_0603_1608Metric_Pad1.08x0.95mm_HandSolder; Tolerance 10%; Voltage Rating 50V; LCSC PN C1588
C15: 47uF; C_1206_3216Metric_Pad1.33x1.80mm_HandSolder; Voltage Rating 25V; Tolerance 10%; LCSC PN C76659
D1: LED; LED_0805_2012Metric_Pad1.15x1.40mm_HandSolder; LCSC PN C2297
D2, D3, D4, D5, D6, D7, D8, D9, D10, D11, D12, D13, D14, D15, D16, D17, D18, D19, D20, D21, D22, D23, D24, D25, D26, D27, D28, D29, D30, D31, D32, D33, D34, D35, D36, D37, D38, D39, D40, D41, D42, D43, D44, D45, D46, D47, D48, D49, D50, D51, D52, D53, D54, D55, D56, D57, D58, D59, D60, D61, D62, D63, D64, D65: BAT54J; D_SOD-323F; LCSC PN C358488
D66: Z2SMBJ18A; D_SMB; LCSC PN C10212
D67: BZT52C12; D_SOD-123; LCSC PN C19077410
F1: Polyfuse; Fuse_1210_3225Metric_Pad1.42x2.65mm_HandSolder; LCSC PN C22379947
H1, H2, H3, H4: MountingHole_Pad; MountingHole_2.2mm_M2_ISO14580_Pad_TopBottom
J1: PWM; JST_ZH_B3B-ZR_1x03_P1.50mm_Vertical_SilkSafe; LCSC PN C495558
J2: DC Supply; BarrelJack_Horizontal; LCSC PN C381116
J3, J4: Conn_01x20; PinSocket_1x20_P2.54mm_Vertical; LCSC PN C5224030
J26: LED6; PinHeader_2x08_P2.54mm_Vertical; LCSC PN C68234
J27: LED5; PinHeader_2x08_P2.54mm_Vertical; LCSC PN C68234
J28: LED7; PinHeader_2x08_P2.54mm_Vertical; LCSC PN C68234
J29: LED8; PinHeader_2x08_P2.54mm_Vertical; LCSC PN C68234
J30: I2C; JST_ZH_B4B-ZR_1x04_P1.50mm_Vertical_SilkSafe; LCSC PN C163034
J31: UART; JST_ZH_B4B-ZR_1x04_P1.50mm_Vertical_SilkSafe; LCSC PN C163034
J32: LED3; PinHeader_2x08_P2.54mm_Vertical; LCSC PN C68234
J33: LED1; PinHeader_2x08_P2.54mm_Vertical; LCSC PN C68234
J34: LED2; PinHeader_2x08_P2.54mm_Vertical; LCSC PN C68234
J35: LED4; PinHeader_2x08_P2.54mm_Vertical; LCSC PN C68234
JP1: Jumper_2_Open; SolderJumper-2_P1.3mm_Open_TrianglePad1.0x1.5mm_Silk
JR1: ROW1; PinHeader_2x08_P2.54mm_Vertical; LCSC PN C68234
JR2: ROW2; PinHeader_2x08_P2.54mm_Vertical; LCSC PN C68234
JR3: ROW3; PinHeader_2x08_P2.54mm_Vertical; LCSC PN C68234
JR4: ROW4; PinHeader_2x08_P2.54mm_Vertical; LCSC PN C68234
JR5: ROW5; PinHeader_2x08_P2.54mm_Vertical; LCSC PN C68234
JR6: ROW6; PinHeader_2x08_P2.54mm_Vertical; LCSC PN C68234
JR7: ROW7; PinHeader_2x08_P2.54mm_Vertical; LCSC PN C68234
JR8: ROW8; PinHeader_2x08_P2.54mm_Vertical; LCSC PN C68234
JSPI1, JSPI2, JSPI3, JSPI4, JSPI5, JSPI6, JSPI7: Conn_01x06; JST_ZH_B6B-ZR_1x06_P1.50mm_Vertical_SilkSafe; LCSC PN C495631
L1: 3.3uH; L_Sunlord_MWSA0604S; Tolerance 20%; LCSC PN C5189747
Q1: AOD4184A; DPAK228P994X240-4N; PARTREV 0; LCSC PN C99124
Q2: MMBT3904; SOT-23; LCSC PN C20526
Q3: AO4407A; SOIC127P600X175-8N; PARTREV I
R1, R5, R30: 10k; R_0603_1608Metric_Pad0.98x0.95mm_HandSolder; Tolerance 1%; LCSC PN C25804
R2: 33.2k; R_0603_1608Metric_Pad0.98x0.95mm_HandSolder; Tolerance 1%; LCSC PN C23003
R3: 1.5k; R_0603_1608Metric_Pad0.98x0.95mm_HandSolder; Tolerance 1%; LCSC PN C543357
R4: 330R; R_0603_1608Metric_Pad0.98x0.95mm_HandSolder; Tolerance 1%; LCSC PN C23138
R6: 47R; R_0603_1608Metric_Pad0.98x0.95mm_HandSolder; Tolerance 1%; LCSC PN C23182
R7, R8, R17: 2.2k; R_0603_1608Metric_Pad0.98x0.95mm_HandSolder; Tolerance 1%; LCSC PN C4190
R9, R10, R11, R12, R13, R14, R15, R16: 3.3k; R_0603_1608Metric_Pad0.98x0.95mm_HandSolder; Tolerance 1%; LCSC PN C22978
R18: 10R; R_0603_1608Metric_Pad0.98x0.95mm_HandSolder; Tolerance 1%; LCSC PN C22859
R19, R20, R21, R22, R23, R24, R25, R26, R27, R28, R29: 4.7k; R_0603_1608Metric_Pad0.98x0.95mm_HandSolder; Tolerance 1%; LCSC PN C23162
TP1, TP2, TP3, TP4, TP5, TP6: TestPoint; TestPoint_Pad_D2.0mm
U1: AP62300TWU; TSOT-23-6; LCSC PN C1883519
U2: CD74HC4067SM96; SSOP-24_5.3x8.2mm_P0.65mm; LCSC PN C98457
U3: LM4040DBZ-3; SOT-23; LCSC PN C460608
U4: RaspberryPi_Pico; RaspberryPi_Pico_Common_THT_CustomSilk
U5, U7: 74HC138; SOIC-16_3.9x9.9mm_P1.27mm; LCSC PN C6818
U6: TM1639 (TA2009B); SOP-24_7.5x15.4mm_P1.27mm; LCSC PN C20611984
U8: CD74HC4051M96; SOIC-16_3.9x9.9mm_P1.27mm; LCSC PN C132065

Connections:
+3V3: C1.1, C2.2, C3.2, C7.2, C9.1, C10.1, C11.1, C12.1, C16.1, J30.1, J31.1, JSPI1.1, JSPI2.1, JSPI3.1, JSPI4.1, JSPI5.1, JSPI6.1, JSPI7.1, L1.2, R2.2, R4.2, R6.1, R7.2, R8.2, R9.1, R10.1, R11.1, R12.1, R13.1, R14.1, R15.1, R16.1, R19.1, R20.1, R21.1, R22.1, R23.1, R24.1, R25.1, R26.1, R27.1, R28.1, R29.1, TP4.1, U2.24 (VCC), U5.16 (VCC), U6.11 (VDD), U7.16 (VCC), U8.16 (VCC)
+9V: C15.1, F1.1, J1.1, J2.1, R3.2
/ADC0: J4.11, U2.1 (COM), U4.31 (GPIO26_ADC0)
/ADC_MUX_A: J4.6, U2.10 (S0), U4.26 (GPIO20)
/ADC_MUX_B: J4.7, U2.11 (S1), U4.27 (GPIO21)
/ADC_MUX_C: J4.9, U2.14 (S2), U4.29 (GPIO22)
/ADC_MUX_D: J3.15, U2.13 (S3), U4.15 (GPIO11)
/AN1: AN1.2, U2.9 (I0)
/AN2: AN2.2, U2.8 (I1)
/AN3: AN3.2, U2.7 (I2)
/AN4: AN4.2, U2.6 (I3)
/AN5: AN5.2, U2.5 (I4)
/AN6: AN6.2, U2.4 (I5)
/AN7: AN7.2, U2.3 (I6)
/AN8: AN8.2, U2.2 (I7)
/AN9: AN9.2, U2.23 (I8)
/AN10: AN10.2, U2.22 (I9)
/AN11: AN11.2, U2.21 (I10)
/AN12: AN12.2, U2.20 (I11)
/AN13: AN13.2, U2.19 (I12)
/AN14: AN14.2, U2.18 (I13)
/AN15: AN15.2, U2.17 (I14)
/AN16: AN16.2, U2.16 (I15)
/COL1: D58.1 (K), D59.1 (K), D60.1 (K), D61.1 (K), D62.1 (K), D63.1 (K), D64.1 (K), D65.1 (K), U7.15 (~Y0)
/COL2: D12.1 (K), D13.1 (K), D30.1 (K), D31.1 (K), D36.1 (K), D40.1 (K), D48.1 (K), D56.1 (K), U7.14 (~Y1)
/COL3: D2.1 (K), D14.1 (K), D27.1 (K), D28.1 (K), D33.1 (K), D41.1 (K), D50.1 (K), D57.1 (K), U7.13 (~Y2)
/COL4: D10.1 (K), D11.1 (K), D24.1 (K), D25.1 (K), D32.1 (K), D38.1 (K), D42.1 (K), D55.1 (K), U7.12 (~Y3)
/COL5: D8.1 (K), D9.1 (K), D22.1 (K), D23.1 (K), D34.1 (K), D39.1 (K), D43.1 (K), D51.1 (K), U7.11 (~Y4)
/COL6: D6.1 (K), D7.1 (K), D20.1 (K), D21.1 (K), D26.1 (K), D44.1 (K), D49.1 (K), D53.1 (K), U7.10 (~Y5)
/COL7: D5.1 (K), D15.1 (K), D17.1 (K), D18.1 (K), D29.1 (K), D37.1 (K), D45.1 (K), D52.1 (K), U7.9 (~Y6)
/COL8: D3.1 (K), D4.1 (K), D16.1 (K), D19.1 (K), D35.1 (K), D46.1 (K), D47.1 (K), D54.1 (K), U7.7 (~Y7)
/COL_MUX_A: J3.1, U4.1 (GPIO0), U7.1 (A0)
/COL_MUX_B: J3.2, U4.2 (GPIO1), U7.2 (A1)
/COL_MUX_C: J3.4, U4.4 (GPIO2), U7.3 (A2)
/CS1: R19.2, U5.15 (~Y0), U6.8 (~STB)
/CS2: JSPI1.5, R20.2, U5.14 (~Y1)
/CS3: JSPI2.5, R21.2, U5.13 (~Y2)
/CS4: JSPI5.5, R22.2, U5.12 (~Y3)
/CS5: JSPI3.5, R23.2, U5.11 (~Y4)
/CS6: JSPI4.5, R24.2, U5.10 (~Y5)
/CS7: JSPI6.5, R25.2, U5.9 (~Y6)
/CS8: JSPI7.5, R26.2, U5.7 (~Y7)
/CS_COL: J4.2, U4.22 (GPIO17), U7.6 (E2)
/CS_ROW: J3.11, U4.11 (GPIO8), U8.6 (~E)
/GRID1: J26.16, J27.16, J28.16, J29.16, J32.16, J33.16, J34.16, J35.16, U6.5 (GRID1)
/GRID2: J26.14, J27.14, J28.14, J29.14, J32.14, J33.14, J34.14, J35.14, U6.4 (GRID2)
/GRID3: J26.12, J27.12, J28.12, J29.12, J32.12, J33.12, J34.12, J35.12, U6.2 (GRID3)
/GRID4: J26.10, J27.10, J28.10, J29.10, J32.10, J33.10, J34.10, J35.10, U6.1 (GRID4)
/GRID5: J26.8, J27.8, J28.8, J29.8, J32.8, J33.8, J34.8, J35.8, U6.24 (GRID5)
/GRID6: J26.6, J27.6, J28.6, J29.6, J32.6, J33.6, J34.6, J35.6, U6.23 (GRID6)
/GRID7: J26.4, J27.4, J28.4, J29.4, J32.4, J33.4, J34.4, J35.4, U6.21 (GRID7)
/GRID8: J26.2, J27.2, J28.2, J29.2, J32.2, J33.2, J34.2, J35.2, U6.20 (GRID8)
/MISO: J4.1, JSPI1.3, JSPI2.3, JSPI3.3, JSPI4.3, JSPI5.3, JSPI6.3, JSPI7.3, R28.2, U4.21 (GPIO16)
/MOSI: J4.5, JSPI1.2, JSPI2.2, JSPI3.2, JSPI4.2, JSPI5.2, JSPI6.2, JSPI7.2, R27.2, U4.25 (GPIO19), U6.6 (DIO)
/PWM_OUT: J4.14, R17.2, TP5.1, U4.34 (GPIO28_ADC2)
/ROW1: JR1.2, JR1.4, JR1.6, JR1.8, JR1.10, JR1.12, JR1.14, JR1.16, R9.2, U8.13 (A0)
/ROW2: JR2.2, JR2.4, JR2.6, JR2.8, JR2.10, JR2.12, JR2.14, JR2.16, R11.2, U8.14 (A1)
/ROW3: JR3.2, JR3.4, JR3.6, JR3.8, JR3.10, JR3.12, JR3.14, JR3.16, R10.2, U8.15 (A2)
/ROW4: JR4.2, JR4.4, JR4.6, JR4.8, JR4.10, JR4.12, JR4.14, JR4.16, R12.2, U8.12 (A3)
/ROW5: JR5.2, JR5.4, JR5.6, JR5.8, JR5.10, JR5.12, JR5.14, JR5.16, R13.2, U8.1 (A4)
/ROW6: JR6.2, JR6.4, JR6.6, JR6.8, JR6.10, JR6.12, JR6.14, JR6.16, R16.2, U8.5 (A5)
/ROW7: JR7.2, JR7.4, JR7.6, JR7.8, JR7.10, JR7.12, JR7.14, JR7.16, R14.2, U8.2 (A6)
/ROW8: JR8.2, JR8.4, JR8.6, JR8.8, JR8.10, JR8.12, JR8.14, JR8.16, R15.2, U8.4 (A7)
/ROW_INPUT: J3.12, U4.12 (GPIO9), U8.3 (A)
/ROW_MUX_A: J3.9, U4.9 (GPIO6), U8.11 (S0)
/ROW_MUX_B: J3.10, U4.10 (GPIO7), U8.10 (S1)
/ROW_MUX_C: J3.5, U4.5 (GPIO3), U8.9 (S2)
/SCL: J3.7, J30.3, R7.1, U4.7 (GPIO5)
/SCLK: J4.4, JSPI1.4, JSPI2.4, JSPI3.4, JSPI4.4, JSPI5.4, JSPI6.4, JSPI7.4, R29.2, U4.24 (GPIO18), U6.7 (CLK)
/SDA: J3.6, J30.2, R8.1, U4.6 (GPIO4)
/SEG1: J33.1, J33.3, J33.5, J33.7, J33.9, J33.11, J33.13, J33.15, U6.12 (SEG1/KS1)
/SEG2: J34.1, J34.3, J34.5, J34.7, J34.9, J34.11, J34.13, J34.15, U6.13 (SEG2/KS2)
/SEG3: J32.1, J32.3, J32.5, J32.7, J32.9, J32.11, J32.13, J32.15, U6.14 (SEG3/KS3)
/SEG4: J35.1, J35.3, J35.5, J35.7, J35.9, J35.11, J35.13, J35.15, U6.15 (SEG4/KS4)
/SEG9: J27.1, J27.3, J27.5, J27.7, J27.9, J27.11, J27.13, J27.15, U6.16 (SEG9)
/SEG10: J26.1, J26.3, J26.5, J26.7, J26.9, J26.11, J26.13, J26.15, U6.17 (SEG10)
/SEG11: J28.1, J28.3, J28.5, J28.7, J28.9, J28.11, J28.13, J28.15, U6.18 (SEG11)
/SEG12: J29.1, J29.3, J29.5, J29.7, J29.9, J29.11, J29.13, J29.15, U6.19 (SEG12)
/SPI_MUX_A: J3.14, U4.14 (GPIO10), U5.1 (A0)
/SPI_MUX_B: J3.19, U4.19 (GPIO14), U5.2 (A1)
/SPI_MUX_C: J3.20, U4.20 (GPIO15), U5.3 (A2)
/SPI_MUX_CS: J4.12, U4.32 (GPIO27_ADC1), U5.6 (E2)
/UART0_RX: J3.17, J31.3, U4.17 (GPIO13)
/UART0_TX: J3.16, J31.2, U4.16 (GPIO12)
GND: AN1.3, AN2.3, AN3.3, AN4.3, AN5.3, AN6.3, AN7.3, AN8.3, AN9.3, AN10.3, AN11.3, AN12.3, AN13.3, AN14.3, AN15.3, AN16.3, C1.2, C2.1, C3.1, C4.1, C5.1, C8.2, C9.2, C10.2, C11.2, C12.2, C13.2, C14.2, C15.2, C16.2, C17.1, D1.1 (K), D66.2 (A), H1.1, H2.1, H3.1, H4.1, J1.3, J2.2, J3.13, J4.13, J30.4, J31.4, JSPI1.6, JSPI2.6, JSPI3.6, JSPI4.6, JSPI5.6, JSPI6.6, JSPI7.6, Q1.3, Q2.2 (E), R1.1, R5.1, R30.1, TP1.1, U1.1 (GND), U2.12 (GND), U2.15 (~E), U3.2 (A), U4.3 (GND), U4.8 (GND), U4.13 (GND), U4.18 (GND), U4.23 (GND), U4.28 (GND), U4.33 (AGND), U4.38 (GND), U5.4 (~E0), U5.5 (~E1), U5.8 (GND), U6.3 (GND), U6.22 (GND), U7.4 (~E0), U7.5 (~E1), U7.8 (GND), U8.7 (VEE), U8.8 (GND)
unnamed: C14.1, Q1.1, R18.1
unnamed: D1.2 (A), R4.1, TP3.1
unnamed: D2.2 (A), JR1.5
unnamed: D3.2 (A), JR1.15
unnamed: D4.2 (A), JR2.15
unnamed: D5.2 (A), JR1.13
unnamed: D6.2 (A), JR2.11
unnamed: D7.2 (A), JR1.11
unnamed: D8.2 (A), JR2.9
unnamed: D9.2 (A), JR1.9
unnamed: D10.2 (A), JR2.7
unnamed: D11.2 (A), JR1.7
unnamed: D12.2 (A), JR1.3
unnamed: D13.2 (A), JR2.3
unnamed: D14.2 (A), JR2.5
unnamed: D15.2 (A), JR2.13
unnamed: D16.2 (A), JR4.15
unnamed: D17.2 (A), JR5.13
unnamed: D18.2 (A), JR4.13
unnamed: D19.2 (A), JR5.15
unnamed: D20.2 (A), JR5.11
unnamed: D21.2 (A), JR4.11
unnamed: D22.2 (A), JR5.9
unnamed: D23.2 (A), JR4.9
unnamed: D24.2 (A), JR5.7
unnamed: D25.2 (A), JR4.7
unnamed: D26.2 (A), JR3.11
unnamed: D27.2 (A), JR5.5
unnamed: D28.2 (A), JR4.5
unnamed: D29.2 (A), JR3.13
unnamed: D30.2 (A), JR5.3
unnamed: D31.2 (A), JR4.3
unnamed: D32.2 (A), JR3.7
unnamed: D33.2 (A), JR3.5
unnamed: D34.2 (A), JR3.9
unnamed: D35.2 (A), JR3.15
unnamed: D36.2 (A), JR3.3
unnamed: D37.2 (A), JR7.13
unnamed: D38.2 (A), JR7.7
unnamed: D39.2 (A), JR7.9
unnamed: D40.2 (A), JR6.3
unnamed: D41.2 (A), JR6.5
unnamed: D42.2 (A), JR6.7
unnamed: D43.2 (A), JR6.9
unnamed: D44.2 (A), JR6.11
unnamed: D45.2 (A), JR6.13
unnamed: D46.2 (A), JR6.15
unnamed: D47.2 (A), JR7.15
unnamed: D48.2 (A), JR7.3
unnamed: D49.2 (A), JR7.11
unnamed: D50.2 (A), JR7.5
unnamed: D51.2 (A), JR8.9
unnamed: D52.2 (A), JR8.13
unnamed: D53.2 (A), JR8.11
unnamed: D54.2 (A), JR8.15
unnamed: D55.2 (A), JR8.7
unnamed: D56.2 (A), JR8.3
unnamed: D57.2 (A), JR8.5
unnamed: D58.2 (A), JR1.1
unnamed: D59.2 (A), JR2.1
unnamed: D60.2 (A), JR3.1
unnamed: D61.2 (A), JR5.1
unnamed: D62.2 (A), JR4.1
unnamed: D63.2 (A), JR7.1
unnamed: D64.2 (A), JR6.1
unnamed: D65.2 (A), JR8.1
unnamed: D66.1 (K), F1.2, JP1.1 (A), Q3.5, Q3.6, Q3.7, Q3.8
unnamed: D67.2 (A), Q3.4, R30.2
unnamed: C4.2, C17.2, D67.1 (K), JP1.2 (B), Q3.1, Q3.2, Q3.3, TP6.1, U1.3 (IN)
unnamed: C13.1, J1.2, Q1.4
unnamed: Q2.1 (B), R5.2, R17.1
unnamed: Q2.3 (C), R3.1, R18.2
unnamed: C6.1, U1.6 (BST)
unnamed: C5.2, U1.5 (EN)
unnamed: C7.1, R1.2, R2.1, U1.4 (FB)
unnamed: C6.2, L1.1, U1.2 (SW)
VDDA: AN1.1, AN2.1, AN3.1, AN4.1, AN5.1, AN6.1, AN7.1, AN8.1, AN9.1, AN10.1, AN11.1, AN12.1, AN13.1, AN14.1, AN15.1, AN16.1, C8.1, J4.15, R6.2, TP2.1, U3.1 (K), U4.35 (ADC_VREF)

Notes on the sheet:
UART Output
I2C Output
Microcontroller (Raspberry Pi Pico)
Keypad and Rotary inputs
SPI Outputs
PWM Output Power Suuply / max 5A
ADC Multiplexers
Power Supply Input 4.2V to 18V Output 3.3V / 3A Max

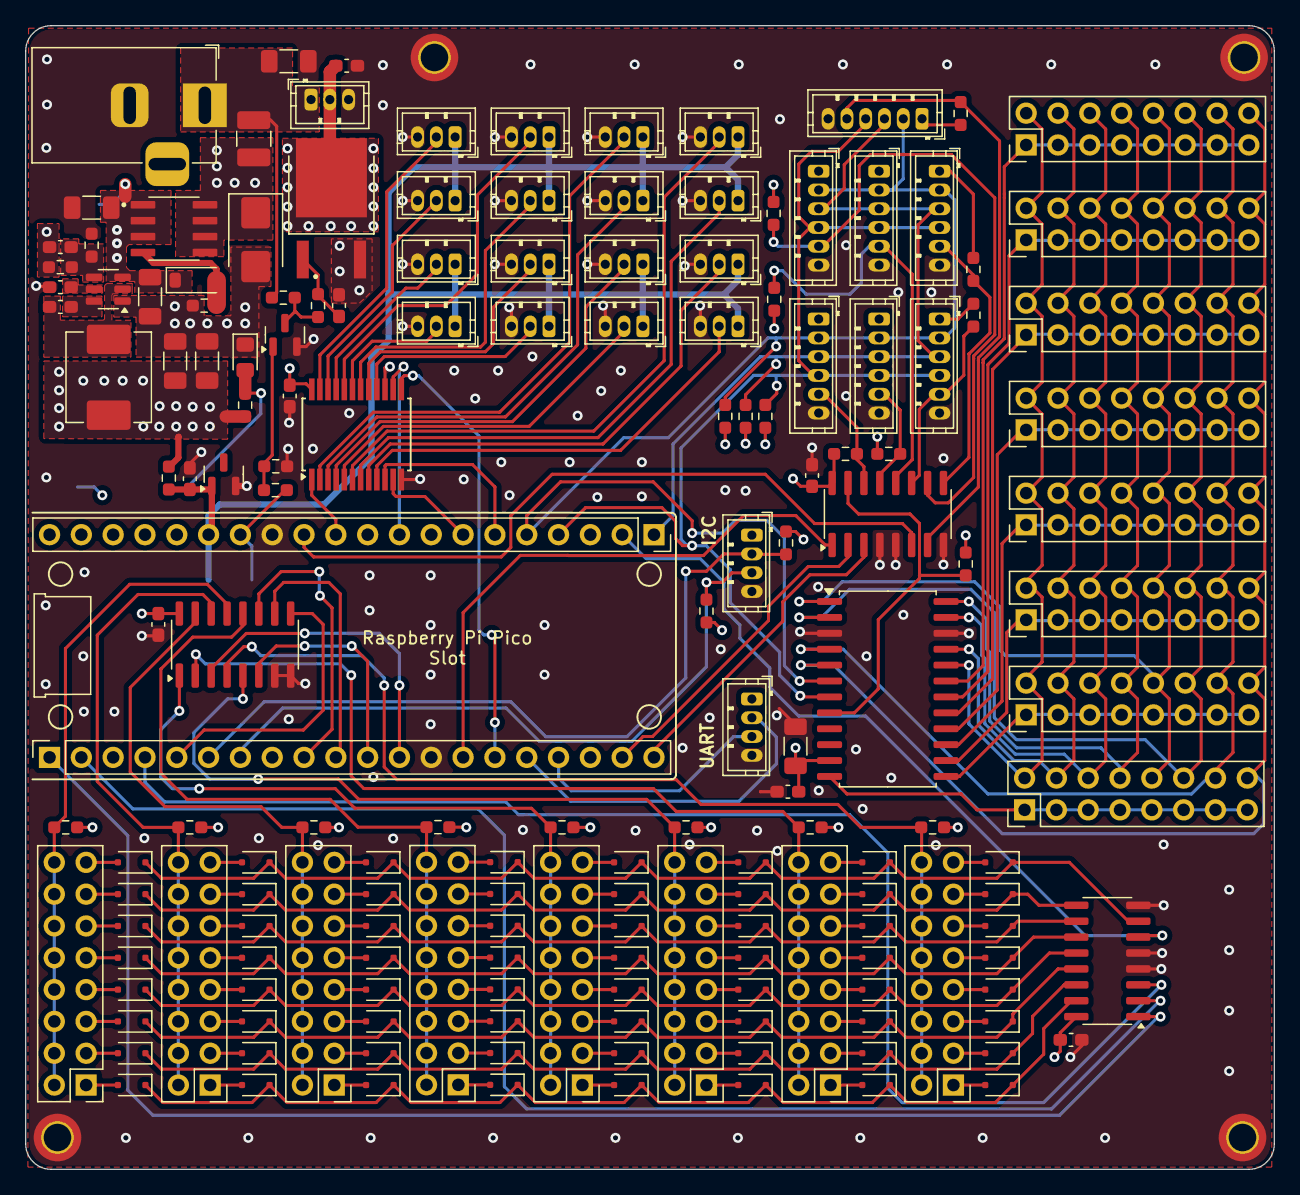
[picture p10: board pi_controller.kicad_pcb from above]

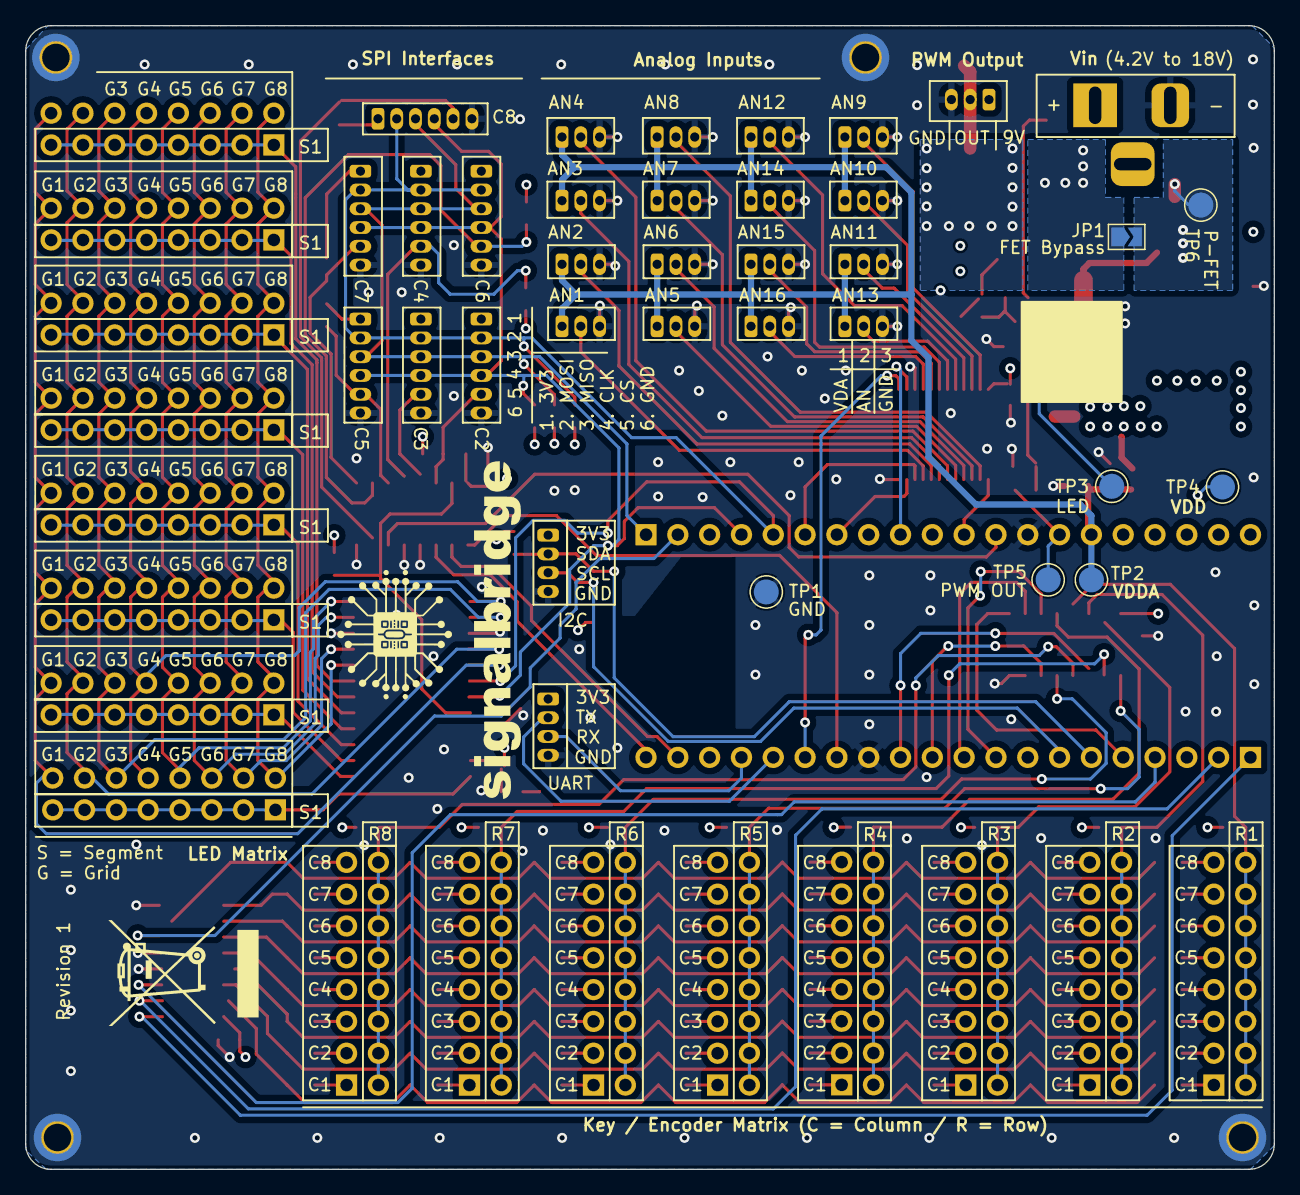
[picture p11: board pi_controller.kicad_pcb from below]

Board: 4 copper layers, 99.7 x 91.3 mm, 182 parts (7 on the bottom side), 162 nets.

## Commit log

2025-03-05 Update layout and rules
    [pi_controller.kicad_pcb, pi_controller.kicad_sch]
2025-03-08 Update routing
    [pi_controller.kicad_pcb, pi_controller.kicad_sch]
2025-03-08 Minor adjustments
    [pi_controller.kicad_pcb]
2025-03-08 Component repositioning to compact form factor
    [pi_controller.kicad_pcb]
2025-03-09 Adjusting DRC checks
    [pi_controller.kicad_pcb, pi_controller.kicad_sch]
2025-03-09 Update PCB footprints
    [pi_controller.kicad_pcb]
2025-03-09 Created gerber for quote and updated layout
    [pi_controller-B_Cu.gbr, pi_controller-B_Mask.gbr, pi_controller-B_Paste.gbr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]
2025-03-09 Adjusting component placement to have more room
    [pi_controller.kicad_pcb]
2025-03-10 Layout ground pour and other adjustments
    [pi_controller.kicad_pcb]
2025-03-10 Refining layout
    [pi_controller.kicad_pcb, pi_controller.kicad_sch]
2025-03-11 Improving PWM circuit
    [pi_controller.kicad_pcb, pi_controller.kicad_sch]
2025-03-11 Adjusting components
    [pi_controller.kicad_pcb, pi_controller.kicad_sch]
2025-03-13 New connectos and adjusted component spacing
    [pi_controller.kicad_pcb, pi_controller.kicad_sch]
2025-03-18 Adjusting footprints for production
    [bom.csv, designators.csv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]
2025-03-19 Changing 10R resistor
    [bom.csv, pi_controller.csv, pi_controller.kicad_pcb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]
2025-07-20 Project name change to signalbridge and board final revision
    [BOM-pi_controller.csv, bom.csv, designators.csv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]
2025-07-21 Changed part number (out of stock)
    [pi_controller.kicad_sch]
2025-07-26 Created the slot for the pi and udpated silk screen
    [BOM-pi_controller.csv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]
2025-08-02 Adjusting testpoint pads and adding 74hc4051 datasheet
    [BOM-pi_controller.csv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]
2026-01-01 Upgrading power supply protection
    [pi_controller.kicad_pcb, pi_controller.kicad_sch]
2026-01-05 Adding power supply protection, ground pour in the top and new 3d models
    [pi_controller.kicad_pcb, pi_controller.kicad_sch]
2026-02-01 Adjusting DRC setting
    [BOM-pi_controller.csv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]
2026-02-01 Add exclude from BOM to testpoint
    [pi_controller.kicad_pcb, pi_controller.kicad_sch]
2026-02-01 Updating images and BOM for JP1
    [pi_controller-CuBottom.gbr, pi_controller-CuIn1.gbr, pi_controller-CuIn2.gbr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]
2026-02-01 Updating production files
    [BOM-pi_controller.csv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]
2026-04-21 chore: consolidate datasheets into a single lowercase folder
    Merge the uppercase Datasheets/ (12 PDFs) into the lowercase datasheets/
    (3 PDFs). The two folders contained disjoint files and were not tracked
    by any code or workflow path; consolidating avoids the case collision
    that is fragile on macOS/Windows and puts every component datasheet in
    one discoverable location.
2026-04-21 docs: move PRODUCTION_CHECKLIST into docs/ and document project layout
    Move PRODUCTION_CHECKLIST.md into a new docs/ folder so long-form docs
    stop accumulating at the root while README.md and LICENSE stay where
    GitHub surfaces them from. Add a Project Structure section to README.md
    that describes what each top-level folder contains and calls out the
    folder names that the KiCad library tables and the release workflow
    depend on, so future contributors do not rename them accidentally.
2026-04-21 Add fabricated board photos to README
2026-04-21 Add fabricated board photos to assets
2026-04-21 Fix fabricated board photos to uniform size in README
2026-04-21 Resize fabricated board photos to uniform height in one row

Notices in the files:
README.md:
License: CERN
